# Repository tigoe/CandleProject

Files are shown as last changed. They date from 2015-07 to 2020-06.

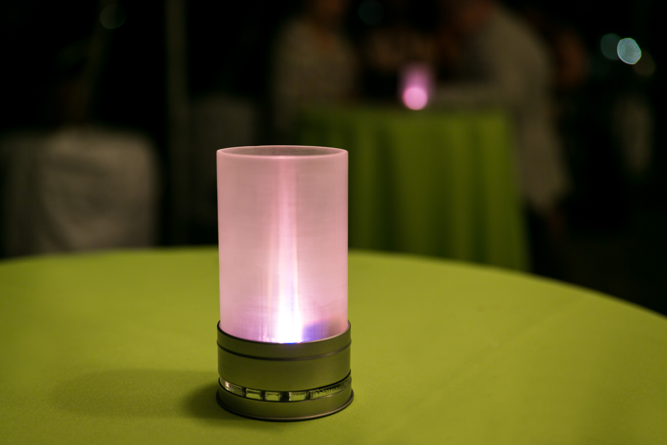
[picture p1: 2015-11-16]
photos/Details_DeniseHand_Aug22_2015-PRINT-Color-23-.jpg

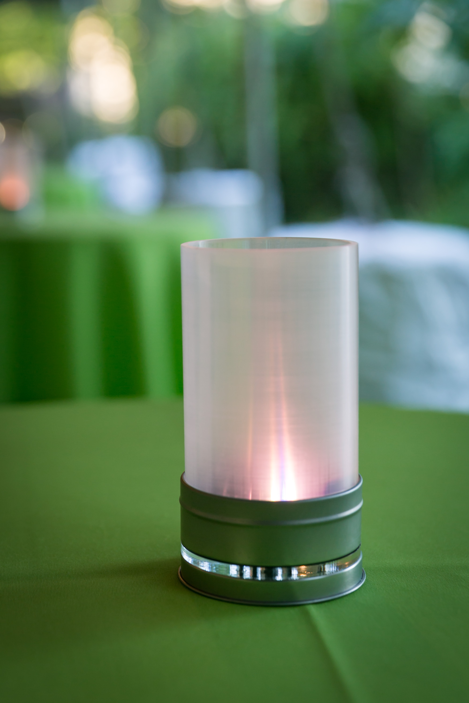
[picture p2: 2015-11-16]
photos/Details_DeniseHand_Aug22_2015-PRINT-Color-05-9458.jpg

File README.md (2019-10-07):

# Candle Project	

This is my candle project. We shall see how it develops.

Tom Igoe <br>
26 June 2015

## Theory of Operation

ESP8266 modules handle the network traffic, and communicate serially to the ATTiny85, which controls the WS2812s. When the candle turns on, it turns two pixels to warm fading, and a thirs to blue. Then the ESP8266 attempts to contact the server. When it succeeds, the third pixel is turned to warm fading.

The metal can of the candle forms a capacitive touch sensor. When a touch is detected, the candle flares the pixels to white, and sends a signal to the server. The server then sends the same message to all the candles, causing them all to flare white. They gradually fade back to the warm glow.

## Communication Protocol

All communications are over UDP. When a new client connects, the server sends "Hello!!!" to the client. When any candle sends a message to the server, the server echoes it to all servers that it's seen since launch.

When a candle receives a * message, it flares white. Similarly, when it receives a touch, it sends a * message.

* Programming

The ATTinys must be removed and programmed with a hardware programmer. The ESP modules can be programmed over the serial connection. The ground of the serial connection is the pin closest to the outside edge of the board. You need to press the IO0 button then the reset on the ESP8266 to put it in programming mode. The  indicator light will grow a dim red when you are in programming mode.

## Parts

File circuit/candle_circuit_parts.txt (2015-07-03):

Partlist

Exported from candle_circuit.brd at 7/3/15 7:48 AM

EAGLE Version 7.3.0 Copyright (c) 1988-2015 CadSoft

Assembly variant: 

Part     Value                      Package                Library             Position (inch)       Orientation

C1       0.1uF                      PANASONIC_C            SparkFun-Capacitors (1.3 0.15)            R180
C2       0.1uF                      PANASONIC_C            SparkFun-Capacitors (1.3 0.7)             R180
D1       MBR120                     SOD-123                microbuilder        (1.13 0.8)            R90
D2       1n4148                     SOD-323                microbuilder        (0.2 0.95)            R0
IC1      TINY10P                    DIL08                  atmel               (0.6 1.65)            R0
JP1      FTDI                       1X06_OVAL              microbuilder        (0.2 1.55)            R90
JP2      Sensor                     1X01                   pinhead             (1.13 1.87)           R0
JP3      POWER                      1X02_OVAL              microbuilder        (1.3 0.95)            R180
JP4      Test                       1X02_OVAL              microbuilder        (1.3 1.14)            R180
JP5      TEST                       1X01                   pinhead             (0.65 0.04)           R0
L1       WS2812B                    WS2812B                adafruit            (0.85 1.25)           R180
L2       WS2812B                    WS2812B                adafruit            (0.55 1.15)           R180
L3       WS2812B                    WS2812B                adafruit            (0.85 1.02)           R0
LED1     RED                        CHIPLED_0805_NOOUTLINE microbuilder        (1.06 0.31)           R90
R1       1k                         R0603                  adafruit            (1.05 0.4)            R180
R2       10k                        R0603                  adafruit            (0.3 0.07)            R0
R3       10k                        R0603                  adafruit            (0.5 0.07)            R0
R4       10k                        R0603                  adafruit            (0.62 0.91)           R0
R5       10k                        R0603                  adafruit            (0.82 0.87)           R0
R6       1M                         R0603                  adafruit            (0.9 1.75)            R270
R7       470                        R0603                  adafruit            (0.95 1.55)           R90
SW1      KMR2                       BTN_KMR2_4.6X2.8       microbuilder        (1.05 0.15)           R270
SW2      KMR2                       BTN_KMR2_4.6X2.8       microbuilder        (1.05 0.55)           R270
U$1      REGULATOR3.3V-UA78M33CDCYR SOT223                 ITP_Lab             (1.3 0.45)            R270
X1       ESP-12                     ESP-12                 adafruit            (0.53 0.47)           R90

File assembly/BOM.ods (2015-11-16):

Part | Value | Package | Vendor | Part No | URL | Unit Cost
 |  | SWITCH SLIDE SPST 3A 125V | Digikey | CWI334-ND | https://www.digikey.com/product-detail/en/GF-123-3011/CWI334-ND/4089772 | 0.564
SW1 | - | AAA Battery Holder | Digikey | BC3AAAW-ND | https://www.digikey.com/product-detail/en/BC3AAAW/BC3AAAW-ND/863319 | 1.472
C1 | 0.1uF | PANASONIC_C | Digikey | PCE3915CT-ND (https://www.digikey.com/product-detail/en/EEE-1HA100WR/PCE3915CT-ND/766291) | https://www.digikey.com/product-detail/en/EEE-1HA100WR/PCE3915CT-ND/766291 | 0.2076
C2 | 0.1uF | PANASONIC_C | Digikey | PCE3915CT-ND (https://www.digikey.com/product-detail/en/EEE-1HA100WR/PCE3915CT-ND/766291) | https://www.digikey.com/product-detail/en/EEE-1HA100WR/PCE3915CT-ND/766291 | 0.2076
D1 | MBR120 | SOD-123 | Digikey | MBR120ESFT1GOSCT-ND (https://www.digikey.com/product-detail/en/MBR120ESFT1G/MBR120ESFT1GOSCT-ND/964525) | https://www.digikey.com/product-detail/en/MBR120ESFT1G/MBR120ESFT1GOSCT-ND/964525 | $0.29
D2 | 1n4148 | SOD-323 | Digikey | 1N4148WSFSCT-ND (https://www.digikey.com/product-detail/en/1N4148WS/1N4148WSFSCT-ND/1873821) | https://www.digikey.com/product-detail/en/1N4148WS/1N4148WSFSCT-ND/1873821 | $0.13
IC1 | TINY10P | DIL08 | Digikey | ATTINY85-20PU-ND (https://www.digikey.com/product-detail/en/ATTINY85-20PU/ATTINY85-20PU-ND/735469) | https://www.digikey.com/product-detail/en/ATTINY85-20PU/ATTINY85-20PU-ND/735469 | $1.35
IC1 | DIL08 socket |  | Digikey | ED58083-ND | https://www.digikey.com/product-detail/en/115-93-308-41-001000/ED58083-ND/218611 | 0.83
JP1 | FTDI | 1X06_OVAL |  | 952-2372-ND (https://www.digikey.com/product-detail/en/M20-9710646/952-2372-ND/3724334) | https://www.digikey.com/product-detail/en/M20-9710646/952-2372-ND/3724334 | 0.1786
JP2 | Sensor | 1X01
JP3 | POWER | 1X02_OVAL
JP4 | Test | 1X02_OVAL
JP5 | TEST | 1X01
L1 | WS2812B | WS2812B | Adafruit |  | https://www.adafruit.com/product/1655 | $4.50
L2 | WS2812B | WS2812B | Adafruit |  | https://www.adafruit.com/product/1655 | $4.50
L3 | WS2812B | WS2812B | Adafruit |  | https://www.adafruit.com/product/1655 | $4.50
LED1 | RED | CHIPLED_0805_NOOUTLINE
R1 | 1k
R2 | 10k | R0603
R3 | 10k | R0603
R4 | 10k | R0603
R5 | 10k | R0603
R6 | 1M
R7 | 470 | R0603
SW1 | KMR2 | BTN_KMR2_4.6X2.8 | Digikey | CKN10246CT-ND (https://www.digikey.com/product-detail/en/KMR231NG%20LFS/CKN10246CT-ND/2176497) | https://www.digikey.com/product-detail/en/KMR231NG%20LFS/CKN10246CT-ND/2176497 | $0.38
SW2 | KMR2 | BTN_KMR2_4.6X2.8 | Digikey | CKN10246CT-ND (https://www.digikey.com/product-detail/en/KMR231NG%20LFS/CKN10246CT-ND/2176497) | https://www.digikey.com/product-detail/en/KMR231NG%20LFS/CKN10246CT-ND/2176497 | $0.38
U$1 | REGULATOR3.3V-UA78M33CDCYR | SOT223 | Digikey | 296-13424-1-ND | https://www.digikey.com/product-detail/en/UA78M33CDCYR/296-13424-1-ND/484495 | $1.09
X1 | ESP-12 | ESP-12 | Adafruit |  | https://www.adafruit.com/products/2491 | $6.95
Subtotal |  |  |  |  |  | $27.53

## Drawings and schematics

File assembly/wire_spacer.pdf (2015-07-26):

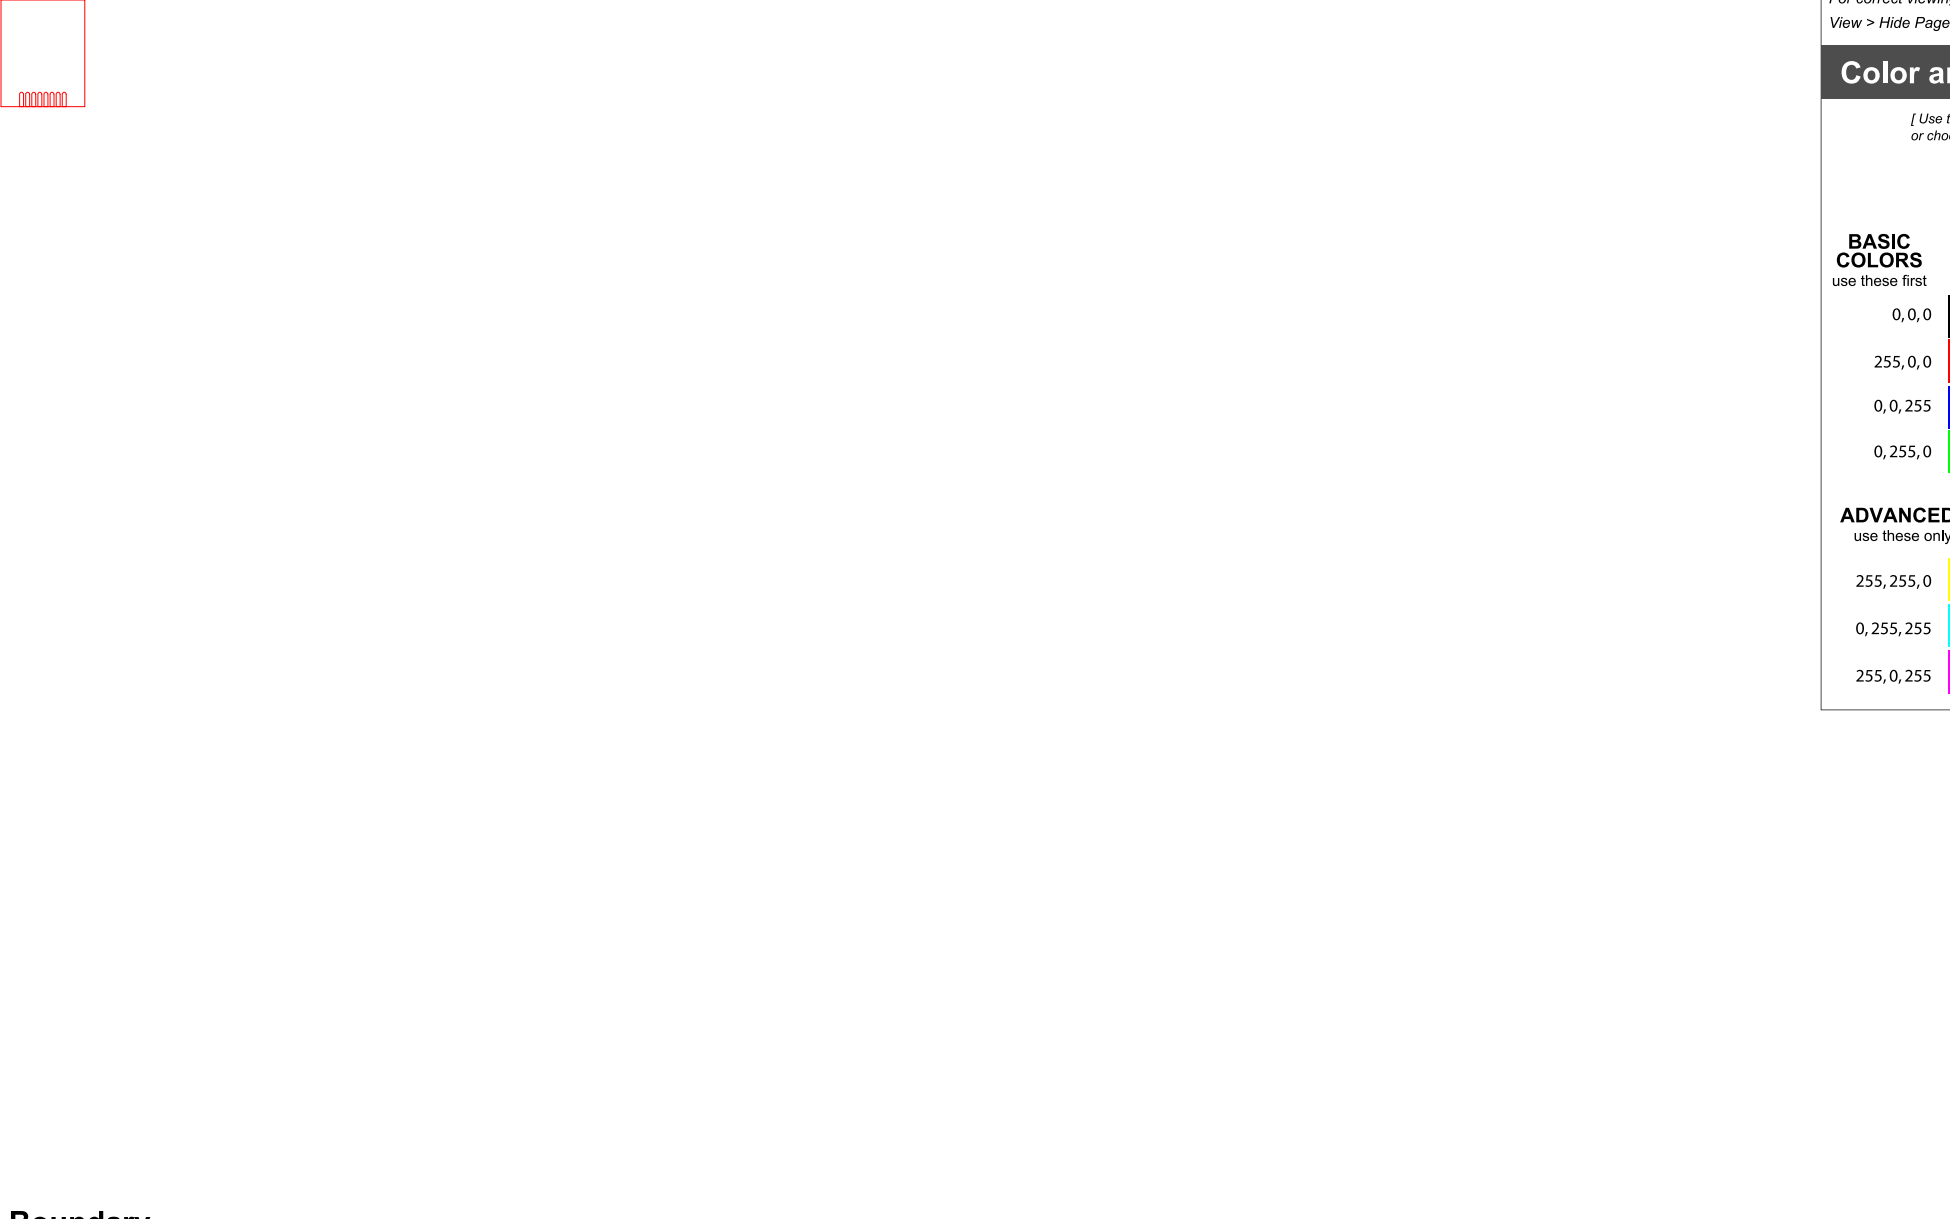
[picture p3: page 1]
marks holes; power leads

Sensor electrode wire

with bolts in them Switch ground wire
(passes through)

Sensor ground wire

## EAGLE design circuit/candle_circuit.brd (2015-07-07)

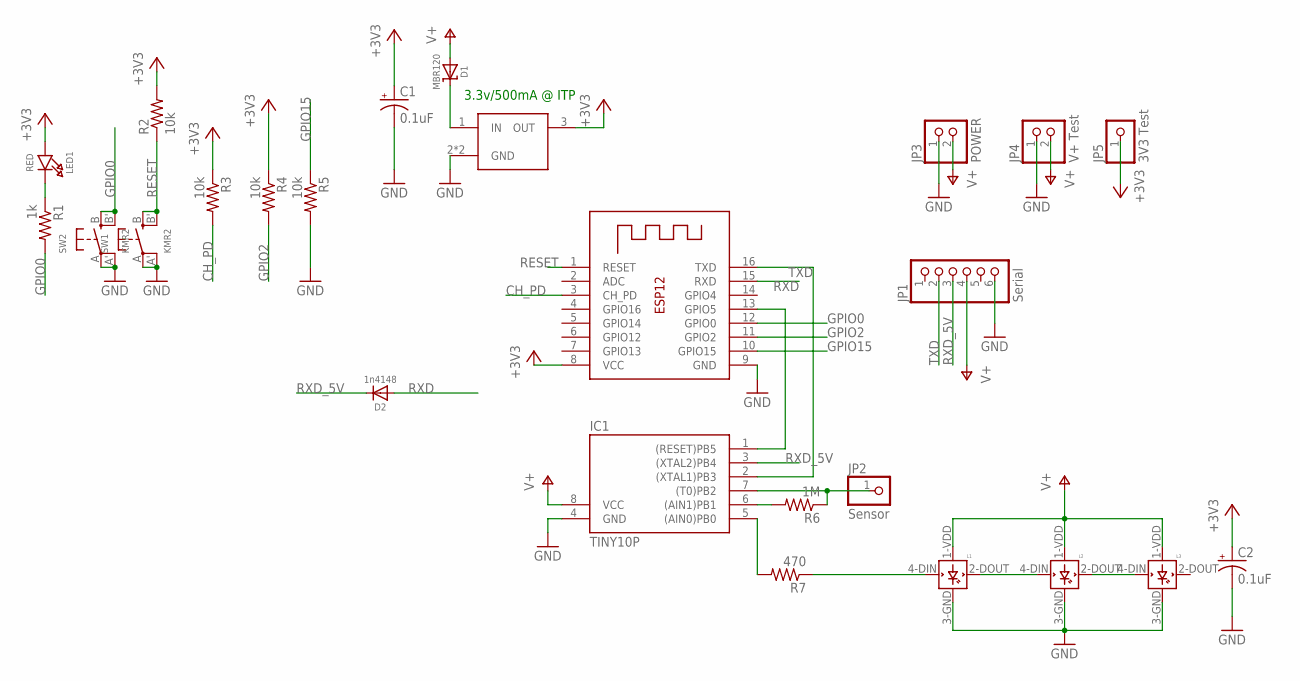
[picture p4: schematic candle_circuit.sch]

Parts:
C1, C2: 0.1uF; PANASONIC_C
D1: MBR120; SOD-123
D2: 1n4148; SOD-323
IC1: TINY10P; DIL08
IC2: ESP-12
JP1: Serial; 1X06_OVAL
JP2: Sensor; 1X01
JP3: POWER; 1X02_OVAL
JP4: V+ Test; 1X02_OVAL
JP5: 3V3 Test; 1X01
L1, L2, L3: WS2812B
LED1: RED; CHIPLED_0805_NOOUTLINE
R1: 1k; R0603
R2, R3, R4, R5: 10k; R0603
R6: 1M; R0603
R7: 470; R0603
SW1, SW2: KMR2; BTN_KMR2_4.6X2.8
U1: REGULATOR3.3V-UA78M33CDCYR; SOT223

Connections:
+3V3: C1.+, C2.+, IC2.8 (VCC), JP5.1, LED1.A, R2.2, R3.1, R4.1, U1.3 (OUT)
CH_PD: IC2.3 (CH_PD), R3.2
GND: C1.-, C2.-, IC1.4 (GND), IC2.9 (GND), JP1.6, JP3.1, JP4.1, L1.3-GND (GND), L2.3-GND (GND), L3.3-GND (GND), R5.2, SW1.A, SW1.A' (P1), SW2.A, SW2.A' (P1), U1.2 (GND), U1.4 (GND)
GPIO0: IC2.12 (GPIO0), R1.2, SW2.B (S), SW2.B' (S1)
GPIO2: IC2.11 (GPIO2), R4.2
GPIO15: IC2.10 (GPIO15), R5.1
unnamed: IC1.5 ((AIN0)PB0), R7.2
unnamed: L1.2-DOUT (DOUT), L2.4-DIN (DIN)
unnamed: L2.2-DOUT (DOUT), L3.4-DIN (DIN)
unnamed: IC1.1 ((RESET)PB5), IC2.13 (GPIO5)
unnamed: D1.C, U1.1 (IN)
unnamed: LED1.C, R1.1
unnamed: IC1.6 ((AIN1)PB1), R6.2
unnamed: L1.4-DIN (DIN), R7.1
RESET: IC2.1 (RESET), R2.1, SW1.B (S), SW1.B' (S1)
RXD: D2.A, IC2.15 (RXD)
RXD_5V: D2.C, IC1.3 ((XTAL2)PB4), JP1.3
SENSOR: IC1.7 ((T0)PB2), JP2.1, R6.1
TXD: IC1.2 ((XTAL1)PB3), IC2.16 (TXD), JP1.2
V+: D1.A, IC1.8 (VCC), JP1.4, JP3.2, JP4.2, L1.1-VDD (VDD), L2.1-VDD (VDD), L3.1-VDD (VDD)

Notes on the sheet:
3.3v/500mA @ ITP

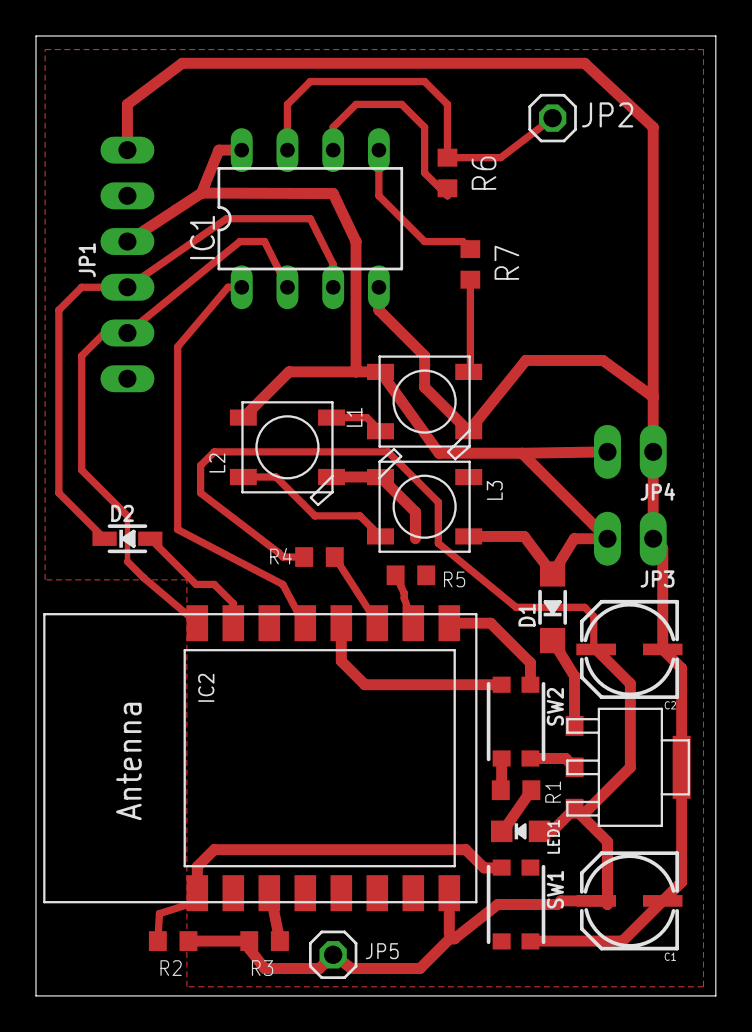
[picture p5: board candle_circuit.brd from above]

Board: 2 copper layers, 37.8 x 53.3 mm, 25 parts (0 on the bottom side), 20 nets.

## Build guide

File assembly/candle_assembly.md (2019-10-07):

# Candle Assembly

Instructions for assembling the candles
## Housing

Spacer: laser cut plexi circle, 3/8", clear, same holes. spacer becomes drilling jug for tins. Always drill from outside of can to inside.

* center hole, 0.25"
* 2 holes either side of center, matching battery housing holes, 0.125"
* 2 holes outside footprint of battery housing, 0.125"

## PCB

right angle female headers for power, sensor electrode, and sensor ground. Sensor headers glue to pcb as needed to stabilise solder joint. Sensor headers should face edge of board. Power header should parallel edge of board.

## Wires

Switch wires will attach to battery pack ground and power connector ground.  Cut one 6" black wire to thread through hole. This and the battery pack black wire will connect to the switch.

power connector: Solder two male headers, 0.1" spacing. one connects to switch black wire, the other to battery pack positive wire. Cut red and black wire to 3" from where they come through the top of the pack. Leave enough slack to connect/disconnect PCB for maintenance and battery changes. Shrink wrap solder joints.

electrode connectors: Cut two wires, one black (6") one white (2"). Solder one end to 1 straight male header each, shrink wrap solder joints. Strip other ends of wires for wrapping around sensor bolt.

## Assembly

1. Thread switch wires (black wire of battery pack and 6" black wire through center hole.
2. Mount battery pack using nylon bolts through mounting holes. Fasten with nylon nuts. Tighten bolts and nuts.
3. Wrap bare end of sensor electrode wire around head of nylon sensor bolt. Then insert in one outer hole. Fasten with metal nut.
4. Thread sensor ground wire through remaining outer hole. Wrap bare end around one of the battey pack bolts underneath nut. With both wires wrapped around bolt, tighten bolts and nuts.
5. solder switch  to ends of switch wires. Shrink wrap ends if possible.
6. glue or double stick tape switch to inside of bottom.
7. attach power connector to PCB
8. Insert batteries.
9. attach PCB to center battery with double-stick tape.
10. Insert candle tube into base
11. Turn on

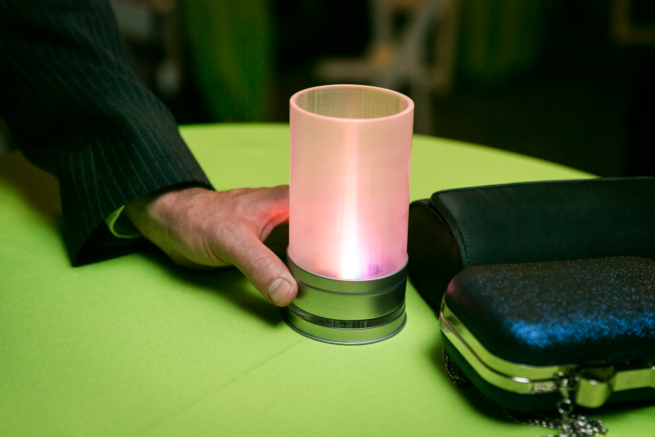
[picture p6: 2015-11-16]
photos/Details_DeniseHand_Aug22_2015-PRINT-Color-16-9763.jpg

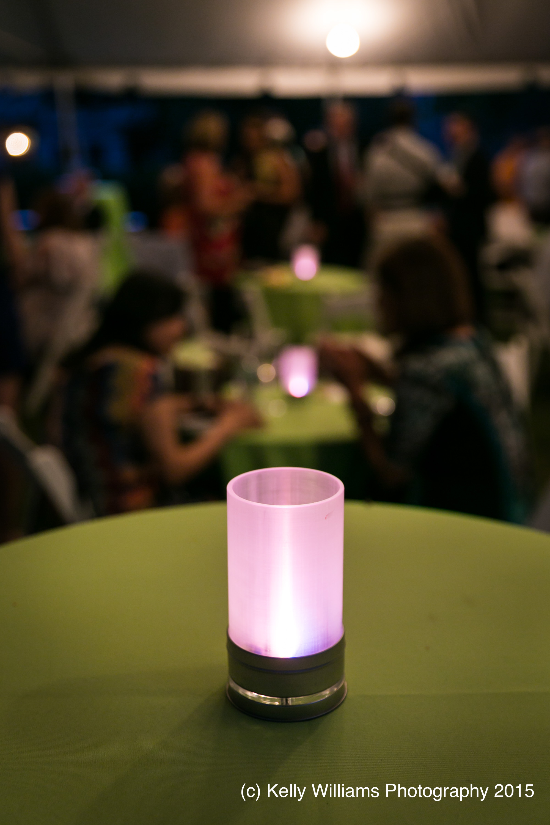
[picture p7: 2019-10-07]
photos/Details_DeniseHand_Aug22_2015-PRINT-Color-14-9730.jpg

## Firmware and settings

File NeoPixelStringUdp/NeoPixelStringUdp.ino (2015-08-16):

/*
  This sketch makes 100 NeoPixels fade in a candle-like behavior.

  created 15 Jun 2015
  modified 16 Jul 2015
  by Tom Igoe

 */
#include <Adafruit_NeoPixel.h>
#include <Console.h>
#include <Bridge.h>
#include <Process.h>

String macAddr = "00:00:00:00:00:00";
char bridgeData[10];
long tenMinutes = 600000;
long loginInterval = 10000;
long lastNetworkMsg = 0;
long lastLogin = 0;
Process udpBridge;

const int neoPixelPin = 3;    // pin that's controlling the neoPixels
const int numPixels = 100;    // count of neoPixels

// initialize neoPixel strip:
Adafruit_NeoPixel strip = Adafruit_NeoPixel(numPixels, neoPixelPin, NEO_RGB + NEO_KHZ800);

// changing range of keyframe colors for the pixels to flicker to:
unsigned long keyColors[] = {0x3E0701, 0x3A0902, 0x2F0F02, 0x370E05};
unsigned long burstColor = 0xFF6633;

unsigned long targetColor[numPixels];    // next target for each pixel
unsigned long pixelColor[numPixels];     // current color for each pixel

// count of keyframe colors:
byte numColors = sizeof(keyColors) / 4;
int flickerInterval = 30;                // in millis, the delay between flicker steps
long lastTwinkle = 0;                    // how long since the last twinkle
boolean online = false;                  // whether the client is online
boolean lightsOn = true;                 // whether the string's on or not

void setup()  {
  Bridge.begin();   // initialize Bridge library
  Console.begin();  // initialize Console library (for debugging)
  Console.println("Starting");
  strip.begin();    // initialize neoPixel strip
  // might be able to do this on Yun startup:
  udpBridge.runShellCommandAsynchronously("python /usr/lib/python2.7/bridge/udpBridge.py");

  randomSeed(millis() + analogRead(A0));
  unsigned long testColor = 0xFF0000;   // initial color is red

  //  set the pixels to red, then green, then blue:
  while (testColor > 0) {
    setStringColor(testColor);
    strip.show();   // refresh the strip
    delay(1000);    // delay to see it:
    // shift the color value down one byte:
    testColor = testColor >> 8;
  }

  strip.show();
  twinkleChase();  // run a twinkle through the whole string
  resetString();
  getMacAddress();
  login();         // log into the server
}

void loop() {
  long currentTime = millis();
  // read for new data:
  readClient();

  // create the flicker effect:
  if (millis() % flickerInterval < 3) {
    flickerPixels();
    randomSeed(currentTime + analogRead(A0));   // reset the randomseed
  }

  if (online == false) {
    strip.setPixelColor(0, 0, 0, 34);  // turn first pixel to low blue
    // attempt to log in:
    if (currentTime - lastLogin > loginInterval) {
      login();
    }
  } else {
    // if you're online and  haven't gotten a server message in ten minutes,
    // assume the server's offline and let the candle controller know:
    if (currentTime - lastNetworkMsg >= tenMinutes) {
      Console.println("~~~");
      online = false;
    }
  }

  // update the strip:
  strip.show();
}

/*
  this function reads client input and interprets it
 */

void readClient() {
  Bridge.get("in", bridgeData, 10);
  String result = String(bridgeData);
  if (result.length() > 0) {
    for (int c = 0; c < result.length(); c++) { // read all bytes of bridgeData
      char input = result[c];
      Console.print(input);
      switch (input) {
        case '*':    // do a twinkle
          twinkleChase();
          Console.println("twinkle");
          lastNetworkMsg = millis();
          break;
        case '!':    // set status to online
          online = true;
          lastNetworkMsg = millis();
          break;
        case '~':    // set status to offline
          lastNetworkMsg = millis();
          online = false;
          break;
        default:  // placeholder for other options here
          break;
      }
    }
    Bridge.put("in", "");
  }
}

void getMacAddress() {
  Process getMac;
  getMac.runShellCommand("ifconfig wlan0 | grep HWaddr");
  while (getMac.running());
  while (getMac.available()) {
    String trash = getMac.readStringUntil('H');
    trash = getMac.readStringUntil(' ');
    macAddr = getMac.readStringUntil('\n');
  }

}

void sendPacket(String message) {
  Process udp;
  String  cmd = "python /usr/lib/python2.7/bridge/udpClient.py 192.168.1.2 \"";
  cmd += message;
  cmd += "\"";
  udp.runShellCommand(cmd);
}

boolean login() {
  Console.println("logging in...");
  getMacAddress();
  // send the MAC address to the server by way of greeting:
  sendPacket(macAddr);
  lastLogin = millis();
}

void resetString() {
  //  set the pixels with colors from the keyColors array:
  for (int pixel = 0; pixel < numPixels; pixel++) {
    pixelColor[pixel] = 0;                           // set the pixel color
    strip.setPixelColor(pixel, pixelColor[pixel]);
  }
  strip.show();
}

/*
  this function shoots a twinkling LED down the whole string:
*/
void twinkleChase() {
  // chase through all the pixels:
  for (int pixel = 0; pixel < numPixels; pixel++) {
    if (pixel > 0) {
      strip.setPixelColor(pixel - 1, pixelColor[pixel]); // reset  lastpixel
    } else {
      strip.setPixelColor(numPixels - 1, pixelColor[pixel]); // reset end pixel
    }

    strip.setPixelColor(pixel, burstColor);  // turn pixel white
    for (int n = 0; n < 9; n++) {            // light nine pixels at a time
      if (pixel + n < numPixels) {
        strip.setPixelColor(pixel + n, burstColor); // turn pixel white
      }
    }
    strip.show();                         // refresh the strip
    delay(10);
  }
}

void setStringColor(unsigned long thisColor) {
  //  set the pixels with colors from the keyColors array:
  for (int pixel = 0; pixel < numPixels; pixel++) {
    pixelColor[pixel] = thisColor;                  // set the pixel color
    strip.setPixelColor(pixel, pixelColor[pixel]);  // set pixel using keyColor
  }
  strip.show();
}

/*
  this function creates the flicker effect:
*/
void flickerPixels() {
  // iterate over all pixels:
  for (int thisPixel = 0; thisPixel < numPixels; thisPixel++) {
    // if the target color matches the current color for this pixel,
    // then pick a new target color randomly:
    if (targetColor[thisPixel] == pixelColor[thisPixel]) {
      int nextColor = random(numColors);
      targetColor[thisPixel] = keyColors[nextColor];
    }
    // fade the pixel one step from the current color to the target color:
    pixelColor[thisPixel] = compare(pixelColor[thisPixel], targetColor[thisPixel]);
    // set the pixel color in the strip:
    strip.setPixelColor(thisPixel, pixelColor[thisPixel]);// set the color for this pixel
  }
}

/*
  takes two colors and returns a color that's a point on each axis (r, g, b)
  closer to the target color
*/
unsigned long compare(unsigned long thisColor, unsigned long thatColor) {
  // separate the first color:
  byte r = thisColor >> 16;
  byte g = thisColor >>  8;
  byte b = thisColor;

  // separate the second color:
  byte targetR = thatColor >> 16;
  byte targetG = thatColor >>  8;
  byte targetB = thatColor;

  // fade the first color toward the second color:
  if (r > targetR) r--;
  if (g > targetG) g--;
  if (b > targetB) b--;

  if (r < targetR) r++;
  if (g < targetG) g++;
  if (b < targetB) b++;

  // combine the values to get the new color:
  unsigned long result = ((unsigned long)r << 16) | ((unsigned long)g << 8) | b;
  return result;
}

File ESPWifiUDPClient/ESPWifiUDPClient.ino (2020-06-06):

/*
  This sketch makes a telnet client on port 8080 to a server
  It echoes any serial bytes to the server, and any server bytes
  to the serial port

  note: the header file "arduino_secrets.h" is included in this repository.
  Include the following variables:
  #define SECRET_SSID "ssid";       // network name
  #define SECRET_PASS "password";   // network password
  #define SECRET_HOST "x.x.x.x";    // server IP address

  created 26 Jun 2015
  modified 7 Oct 2019
  by Tom Igoe

*/

#include <ESP8266WiFi.h>
#include <WiFiUdp.h>
#include "arduino_secrets.h"

WiFiClient client;
WiFiUDP Udp;

const int port = 8888;
byte mac[6];
long tenMinutes = 600000;
int loginInterval = 10000;
long lastNetworkMsg = 0;
long lastLogin = 0;
boolean online = false;

void setup() {
  pinMode(5, OUTPUT);
  Serial.begin(9600);
  Serial.setTimeout(10);
  Udp.setTimeout(10);
  connectToRouter();
}


void loop() {
  long currentTime = millis();

  // if there's data available, read a packet
  int packetSize = Udp.parsePacket();
  if (packetSize) {
    // if there's a UDP packet, read it:
    while (Udp.available()) {
      String line = Udp.readStringUntil('\n');
      Serial.print(line);
    }
    lastNetworkMsg = millis();
    online =  true;
  }

  // Read all the lines of the reply from server and print them to Serial
  while (Serial.available()) {
    String line = Serial.readStringUntil('\n');
    // send the MAC address to the server by way of greeting:
    Udp.beginPacket(SECRET_HOST, 8888);
    Udp.println(line);
    Udp.endPacket();
  }

  // if you're not connected to the router, attempt to reconnect:
  if (WiFi.status() != WL_CONNECTED) {
    connectToRouter();
    online = false;
  }

  if (online == false) {
    // attempt to log in:
    if (currentTime - lastLogin > loginInterval) {
      login();
    }
  } else {
    // if you're online and  haven't gotten a server message in ten minutes,
    // assume the server's offline and let the candle controller know:
    if (currentTime - lastNetworkMsg >= tenMinutes) {
      Serial.println("~~~");
      online = false;
    }
  }
}

void connectToRouter() {
  // let the ATTiny start:
  delay(100);
  online = false;
  //inform the ATTiny that you're offline
  Serial.println("~~~");
  Serial.print("Connecting to ");   // connect to access point
  Serial.println(SECRET_SSID);
  WiFi.begin(SECRET_SSID, SECRET_PASS);

  digitalWrite(5, LOW);     // hold the ATTiny in reset until you connect
  while (WiFi.status() != WL_CONNECTED) {
    delay(1000);
    Serial.print(".");
  }
   digitalWrite(5, HIGH);       // activate the ATtiny
  // when connected to access point, acknowledge it:
  Serial.println("");
  Serial.println("WiFi connected");
  Serial.println("IP address: ");
  Serial.println(WiFi.localIP());
  delay(100);
  login();
}

boolean login() {
  Serial.println("logging in");
  Udp.begin(port);
  // This will send the MAC address to the server:
  WiFi.macAddress(mac);             //get your MAC address
  String macAddr;                   // a string to convert it for sending
  for (int i = 0; i < 5; i++) {     // iterate over the MAC address
    if (mac[i] < 0x10) {            // add a leading 0 to single-digit hex numbers
      macAddr += "0";
    }
    macAddr += String(mac[i], HEX); // get the byte, convert to hex string
    macAddr += ":";                 // add a :
  }
  if (mac[5] < 0x10) {             // add a leading 0 to single-digit hex numbers
    macAddr += "0";
  }
  macAddr += String(mac[5], HEX);               // add the final byte

  // send the MAC address to the server by way of greeting:
  Udp.beginPacket(SECRET_HOST, 8888);
  Udp.println(macAddr);
  Udp.endPacket();
  lastLogin = millis();
}

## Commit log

2015-06-27 include circuit diagrams
    [CandleCircuit.fzz]
2015-06-27 updated sensor threshold
2015-06-30 Added eagle files
    [candle_circuit.brd, candle_circuit.sch]
2015-06-30 updated parts, and started board layout
2015-07-02 Updates to circuit, client
    [candle_circuit.brd, candle_circuit.sch]
2015-07-02 about to cut
2015-07-03 Circuit board updates
    [candle_circuit.brd, candle_circuit.sch]
2015-07-03 board update
    [candle_circuit.sch]
2015-07-03 Board updates
    [candle_circuit.brd, candle_circuit.sch]
2015-07-03 changes to client and candle driver
2015-07-03 Deleted Fritzing version
    [CandleCircuit.fzz]
2015-07-03 Updates to board and schematic
    [candle_circuit.brd, candle_circuit.sch]
2015-07-07 Updates to client
    [candle_circuit.brd]
2015-07-10 updated twinkle threshold in candle driver
2015-07-16 Added spacer construction draeing
2015-07-17 Added assembly instructions
2015-07-26 added various assembly files
2015-07-26 updated candle driver code
2015-07-26 Updated candle driver
2015-11-16 updated BOM and assembly details
    [BOM.ods]
2019-10-07 updated candle assembly and readme.md

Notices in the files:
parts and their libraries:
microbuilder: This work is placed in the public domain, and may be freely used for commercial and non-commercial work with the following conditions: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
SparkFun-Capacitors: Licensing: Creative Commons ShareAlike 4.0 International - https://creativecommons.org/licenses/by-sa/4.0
